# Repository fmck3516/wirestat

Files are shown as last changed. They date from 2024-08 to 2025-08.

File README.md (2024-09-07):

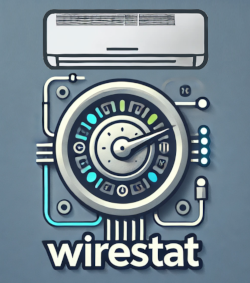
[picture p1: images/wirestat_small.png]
wirestat


# wirestat

## What is it?

wirestat is a compact gadget that bridges the gap between traditional wired household thermostats and ductless mini split
systems. With wirestat, you can control your mini split using familiar thermostats, whether it's an old-school thermostat
like Honeywell or a smart thermostat like Nest or Ecobee.

Why did I create wirestat?

- I wanted a consistent thermostat experience for my central AC and mini splits.
- I prefer traditional thermostats to smartphone apps and remote controls.
- I was frustrated by the lack of precise control over temperature swings and other settings.
- Ultimately, I wished I could use a regular household thermostat for my mini split.

## What is it not?

wirestat is not another smart thermostat. It is actually pretty dumb: 
- No buttons.
- No app.
- No internet.

## Is it for sale?

At this point in time, wirestat is a DIY project: All parts have to be sourced and assembled
yourself. I might create and sell a small batch at cost some time in the future. Please get in
touch with me (see contact section below) if you are interested in a physical copy.

## How does it work?

wirestat continuously monitors your thermostat. When it detects a call (e.g., a call for cooling), it relays the command
to your mini split's indoor unit (IDU) via an infrared signal.

Examples:
- Thermostat calls for Stage 1 Cooling -> send "Cool / 70 Degree / Fan Low" to IDU
- Thermostat calls for Stage 2 Cooling -> send "Cool / 70 Degree / Fan Auto" to IDU
- Thermostat calls for Fan => send "Fan Auto" to IDU

## Media

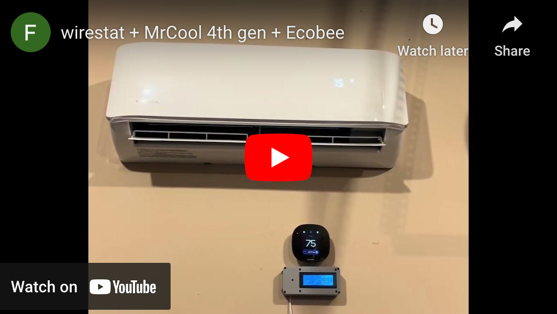
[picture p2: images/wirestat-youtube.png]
wirestat video (http://www.youtube.com/watch?v=b3PyWUqDRN4 "wirestat + MrCool 4th gen + Ecobee")


wirestat in action

wirestat disassembled

### Configuration

wirestat supports the following inputs:

| Symbol | Descr |
|---|---|
| G1 | Fan (stage 1) |
| G2 | Fan (stage 2) |
| G3 | Fan (stage 3) |
| Y1 | Cooling (stage 1) |
| Y2 | Cooling (stage 2) |
| W1 | Heating (stage 1) |
| W2 | Heating (stage 2) |

It's fine if you thermostat does not support all of the above inputs. If you thermostat only supports a single stage for
fan, cooling and heating, you only need to wire G1, Y1 and W1.

Each relevant input scenario is mapped to an infrared signal for the IDU.

Example:

| G1  | G2  | G3  | Y1  | Y2  | W1  | W2  | Infrared Signal for IDU |
|-----|-----|-----|-----|-----|-----|-----|---|
| 0 | 0 | 0 | 0 | 0 | 0 | 0 | OFF |
| 1 | 0 | 0 | 0 | 0 | 0 | 0 | Fan (low) |
| ... | ... | ... | ... | ... | ... | ... | ... |
| 0/1 | 0/1 | 0/1 | 1 | 0 | 0 | 0 | Cool (72F) / Fan (low)  |
| 0/1 | 0/1 | 0/1 | 0 | 1 | 0 | 0 | Cool (72F) / Fan (high) |
| ... | ... | ... | ... | ... | ... | ... | ... |

# Resources

## :warning: Warning :warning:

wirestat is an experimental hobby project. I've put it together without a background in electrical engineering - use the
provided circuit, firmware and enclosure at your own risk.

## Firmware

The firmware was developed using the [Arduino IDE](https://www.arduino.cc/en/software).

Source: [wirestat.ino](firmware/wirestat/wirestat.ino)

## Schematics

The schematics were drawn in [KiCad](https://www.kicad.org). 

Source: [wirestat.kicad_sch](schematics/wirestat.kicad_sch)

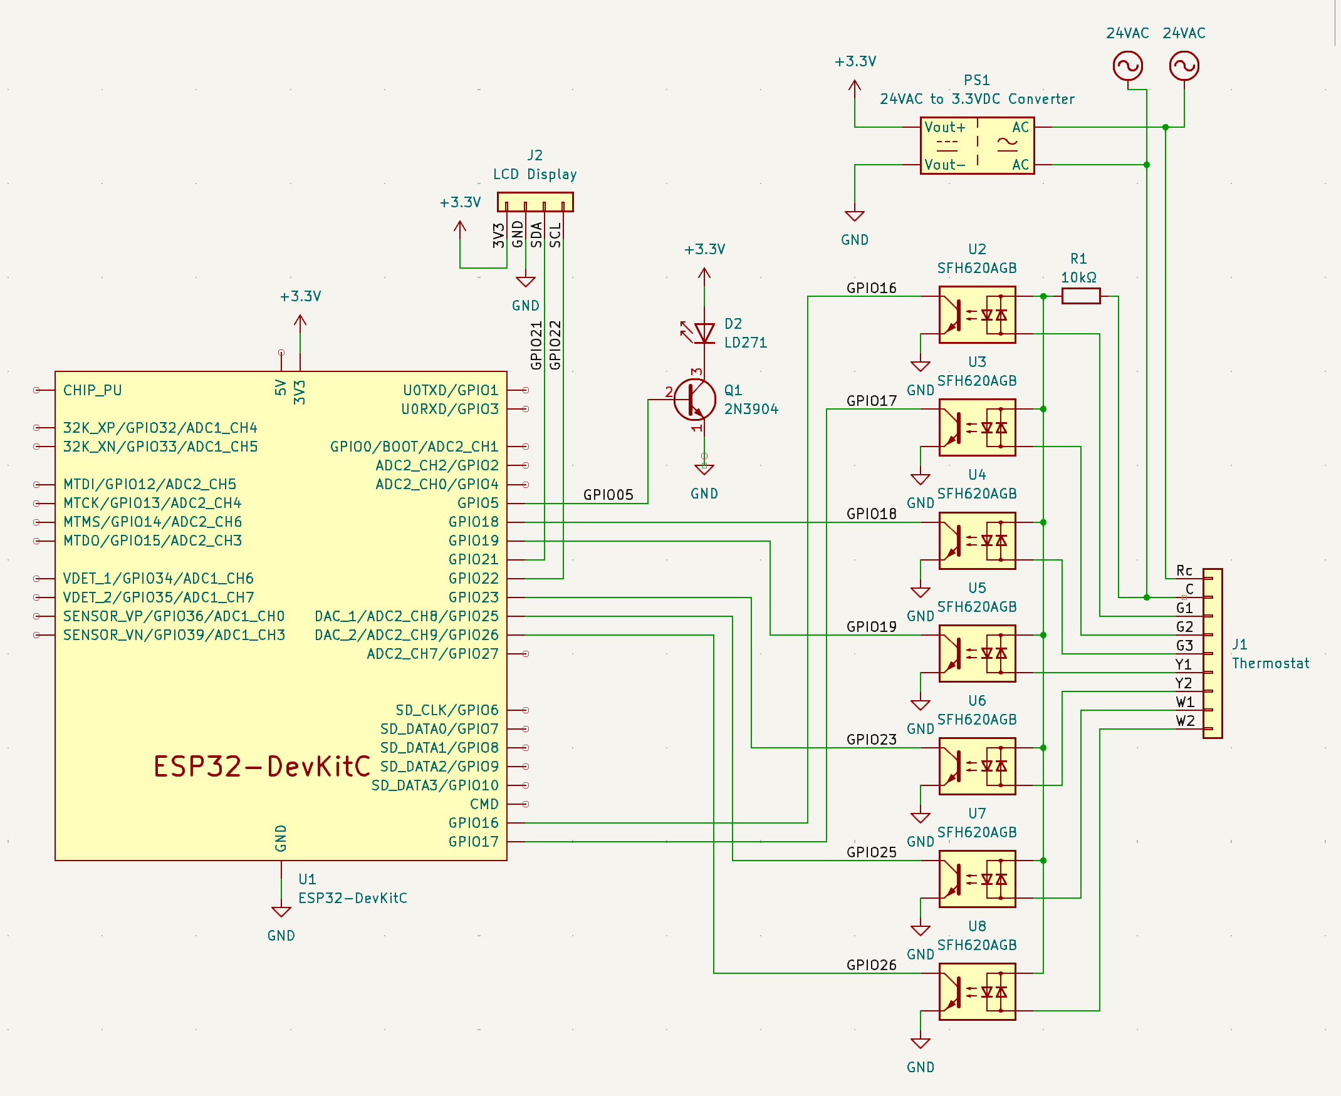
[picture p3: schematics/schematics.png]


## Enclosure

The enclosure was designed in [Blender](https://www.blender.org) and printed on a
[Bambu Lab X1 Carbon](https://bambulab.com/en-us/x1) 3D printer.

Blender file:
- [enclosure.blend](enclosure/enclosure.blend)

STL exports:
- [base.stl](enclosure/base.stl)
- [lid.stl](enclosure/lid.stl)
- [thermostat-cover-plate.stl](enclosure/thermostat-cover-plate.stl)

## Power Supply

wirestat operates on a 24V AC input, making it fully compatible with the standard power supply used by regular household
thermostats.

You have two options to power wirestat:

- Utilize the existing power supply of your thermostat, or
- Purchase an [AC 24 Volt Transformer](https://www.amazon.com/dp/B07DJ7RHS5) to power both wirestat and your thermostat.

## Parts List

I've sources some components (e.g., the transistor and infrared LED) from existing boards and Arduino starter kits. 
Accordingly, I do not have a datasheet for those components.  

| Symbol | Confirmed | Description | Count | Unit Price | Total  |
|---|---|---|---|---|---|
| U1 | :white_check_mark: | [ESP32 Development Board](https://www.amazon.com/gp/product/B0718T232Z) | 1 | $9.99 | $9.99  |
| U2-U8  | :white_check_mark: | [SFH620AGB Optoinsulator](https://www.digikey.com/en/products/detail/vishay-semiconductor-opto-division/SFH620AGB/4074947) | 7 | n/a | $4.22  |
| R1 | :white_check_mark: | [10 kΩ Resistor](https://www.digikey.com/en/products/detail/yageo/MF0207FRE52-10K/9124672) | 1 | $0.10 | $0.10  |
| Q1 | :grey_question: | [2N3904 NPN Transistor](https://www.digikey.com/en/products/detail/diotec-semiconductor/2N3904/13164701) | 1 | $0.13 | $0.13  |
| D2 | :grey_question: | [IR LED 940NM](https://www.digikey.com/en/products/detail/lumex-opto-components-inc/OED-EL-1L2/270797) | 1 | $0.58 | $0.58  |
| PS1 | :white_check_mark: | [AC to DC Buck Step Down Converter](https://www.amazon.com/dp/B0983GW7YJ) | 1 | n/a | $8.99  |
| PS1 | :white_check_mark: | [20x4 I2C LCD Module](https://www.amazon.com/dp/B01GPUMP9C) | 1 | $12.99 | $12.99 |

# Reverse engineering of infrared commands

I used [IRrecvDumpV2](https://github.com/crankyoldgit/IRremoteESP8266/blob/master/examples/IRrecvDumpV2/IRrecvDumpV2.ino)
to reverse engineer the infrared commands for my indoor unit.

# Open Questions

## Resistors for the infrared LED

Based on my little bit of research, it is required to include the following resistors:

- A ~220Ω resistor between GPIO 5 and the transistor's base.
- A ~22Ω resistor between +3.3V and the infrared LED's anode.

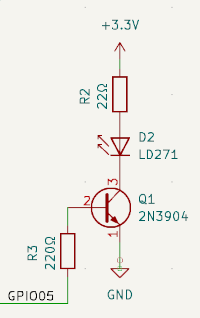
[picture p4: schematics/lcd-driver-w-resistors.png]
LCD driver with resistors


However, the circuit suggested in the [IR Sending](https://github.com/crankyoldgit/IRremoteESP8266/wiki#ir-sending) 
guide connects the transistor and infrared LED directly to the pins of the NodeMCU board:

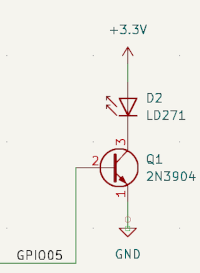
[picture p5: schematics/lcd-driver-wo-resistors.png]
LCD driver w/o resistors


The circuit operates effectively without resistors, and their absence notably extends the LED's range. I conducted a 
24-hour stress test, during which the circuit continuously transmitted infrared signals. Both the transistor and the LED
performed reliably throughout. Therefore, I've decided to proceed with the sub-circuit without resistors for now.

# References

- [Detecting 24V AC with an ESP32](https://www.youtube.com/watch?v=C4kNbcueWMxM)
- [IR Sending](https://github.com/crankyoldgit/IRremoteESP8266/wiki#ir-sending)

# Contributions / Contact

Contributions are always welcome! You can either

- submit a pull request,
- create an issue in GitHub's issue tracker or
- reach out via email at ${firstname}.${lastname}@gmail.com (replacement of placeholders left as exercise to the reader).

I would love to hear from you.

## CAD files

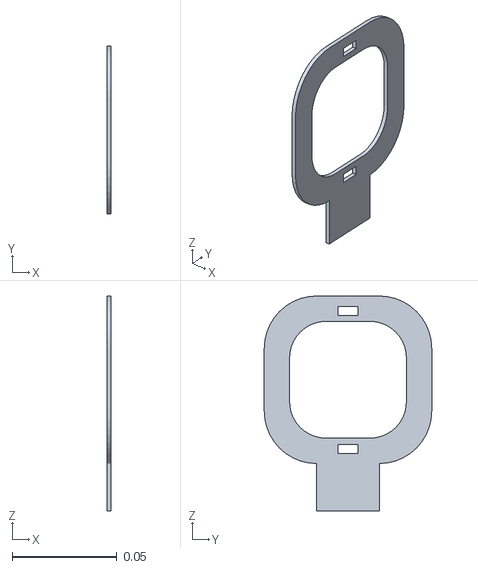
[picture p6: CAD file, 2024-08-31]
enclosure/thermostat-cover-plate.stl
0.002 x 0.08 x 0.103

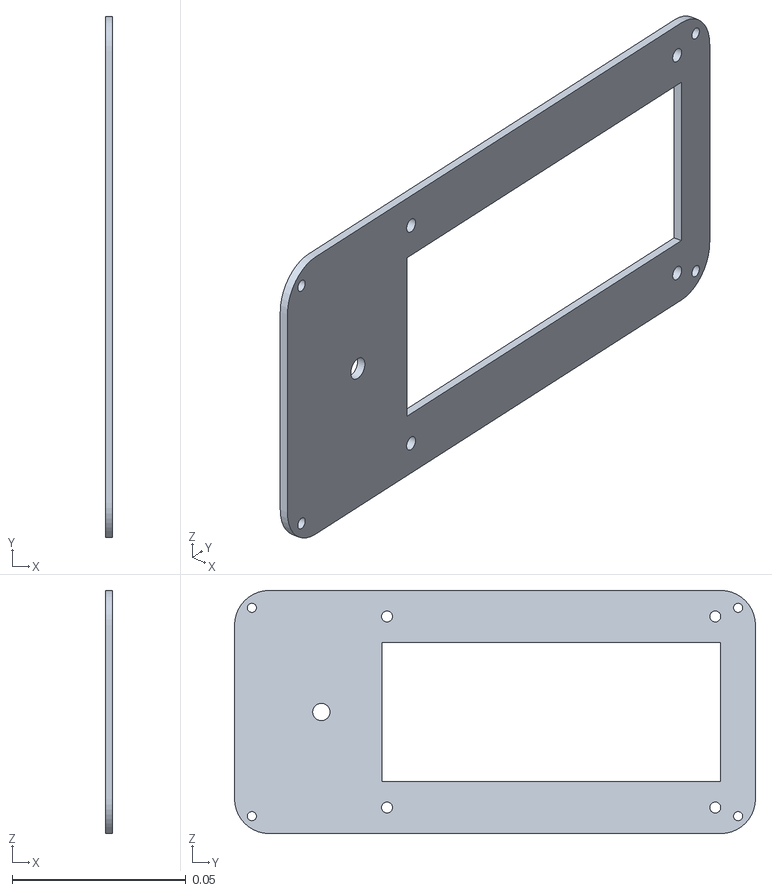
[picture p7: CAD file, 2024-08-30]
enclosure/lid.stl
0.002 x 0.15 x 0.07

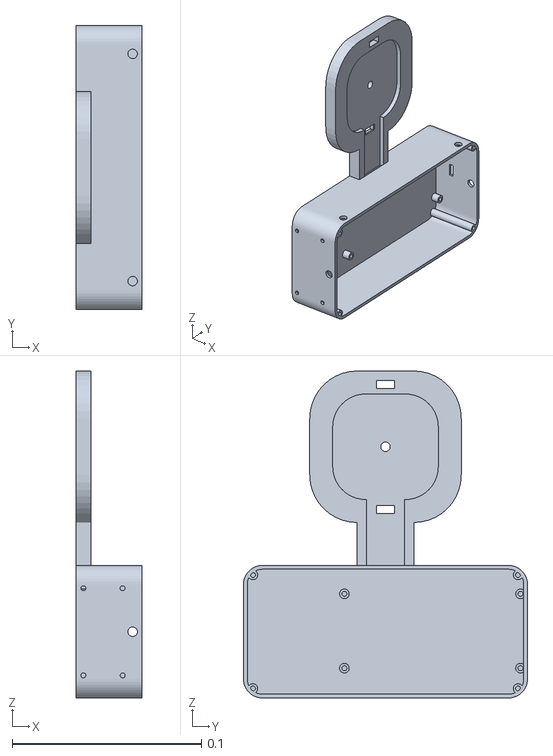
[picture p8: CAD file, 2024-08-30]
enclosure/base.stl
0.035 x 0.15 x 0.173

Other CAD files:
enclosure/enclosure.blend

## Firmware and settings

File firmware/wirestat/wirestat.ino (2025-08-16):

/*
  Copyright 2024 the original author or authors.

  Licensed under the Apache License, Version 2.0 (the "License");
  you may not use this file except in compliance with the License.
  You may obtain a copy of the License at

    https://www.apache.org/licenses/LICENSE-2.0

  Unless required by applicable law or agreed to in writing, software
  distributed under the License is distributed on an "AS IS" BASIS,
  WITHOUT WARRANTIES OR CONDITIONS OF ANY KIND, either express or implied.
  See the License for the specific language governing permissions and
  limitations under the License.
*/

#include <IRremoteESP8266.h>
#include <IRsend.h>
#include <LiquidCrystal_I2C.h>

const uint16_t PIN_IR_TRANSMITTER = 5;
const uint16_t PIN_SDA = 21;
const uint16_t PIN_SCL = 22;
const uint16_t PIN_THERMOSTAT[] = {
  16 /* G1 */, 
  17 /* G2 */, 
  18 /* G3 */, 
  19 /* Y1 */, 
  23 /* Y2 */, 
  25 /* W1 */, 
  26 /* W2 */ 
};

const int DEBOUNCE_INTERVAL_MS = 2000;

long long PIN_LAST_ACTIVE[] = { 
  -DEBOUNCE_INTERVAL_MS /* G1 */, 
  -DEBOUNCE_INTERVAL_MS /* G2 */, 
  -DEBOUNCE_INTERVAL_MS /* G3 */, 
  -DEBOUNCE_INTERVAL_MS /* Y1 */, 
  -DEBOUNCE_INTERVAL_MS /* Y2 */, 
  -DEBOUNCE_INTERVAL_MS /* W1 */, 
  -DEBOUNCE_INTERVAL_MS /* W2 */ 
};

const int G1 = 0;
const int G2 = 1;
const int G3 = 2;
const int Y1 = 3;
const int Y2 = 4;
const int W1 = 5;
const int W2 = 6;

const int CALL_UNKNOWN = 0;
const int CALL_OFF = 1;
const int CALL_FAN = 2;
const int CALL_COOL_STAGE_1 = 3;
const int CALL_COOL_STAGE_2 = 4;
const int CALL_HEAT_STAGE_1 = 5;
const int CALL_HEAT_STAGE_2 = 6;

const int LCD_COLUMNS = 20;
const int LCD_ROWS = 4;
const int LCD_ADDRESS = 0x27;

/*
  The number of calls to store. Must be at least 2 to store
  - the candidate call and
  - the active call
*/
const int CALL_HISTORY = 5;

/*
  History of the last ${CALL_HISTORY} calls:

  call[0]: the candidate call (that might be promoted to active or replaced with the next candidate call)
  call[1]: the active call
  call[2]: the previous call
  call[3]: the pre-previous call
  ...
*/
int call[CALL_HISTORY];

/*
  The timestamps when the calls started. 
*/
unsigned long callStart[CALL_HISTORY];

const int CALL_IDX_CAND = 0;
const int CALL_IDX_ACTIVE = 1;
const int CALL_IDX_PREV = 2;
const int CALL_IDX_PPRV = 3;
const int CALL_IDX_P3RV = 4;

const unsigned long RESEND_INTERVAL =  1UL *  1UL * 15UL * 60UL * 1000UL; // 15 minutes
const unsigned long REBOOT_INTERVAL =  7UL * 24UL * 60UL * 60UL * 1000UL; // 7 days

unsigned long lastMessageSentAt = 0;

IRsend irsend(PIN_IR_TRANSMITTER);
LiquidCrystal_I2C lcd(0x27, LCD_COLUMNS, LCD_ROWS);

//
// The following codes have been recorded using https://github.com/crankyoldgit/IRremoteESP8266
//
const uint64_t MR_COOL_GEN4_OFF =                 0xA10C7EFFFFF3;
const uint64_t MR_COOL_GEN4_FAN_LOW =             0xA18C7EFFFF73;
const uint64_t MR_COOL_GEN4_COOL_75F_FAN_LOW =    0xA1886DFFFF6D;
const uint64_t MR_COOL_GEN4_COOL_75F_FAN_MEDIUM = 0xA1906DFFFF7D;
const uint64_t MR_COOL_GEN4_HEAT_75F_FAN_LOW =    0xA18B6DFFFF6F;
const uint64_t MR_COOL_GEN4_HEAT_75F_FAN_HIGH =   0xA19B6DFFFF77;


void setup() {
  irsend.begin();
  Serial.begin(115200, SERIAL_8N1);
  for (int i = 0; i < sizeof call / sizeof call[0]; i++) {
    call[i] = CALL_UNKNOWN;
    callStart[i] = 0;
  }
  for (int i = 0; i < sizeof PIN_THERMOSTAT / sizeof PIN_THERMOSTAT[0]; i++) {
    pinMode(PIN_THERMOSTAT[i], INPUT_PULLUP);
  }
  lcd.init();
  lcd.backlight();
  lcd.clear();  
}

void loop() {
  readThermostat();
  displayCallHistory();

  // reboot every week
  if (millis() >= REBOOT_INTERVAL) {
    ESP.restart();
  }

  // repeat current call every 15 minutes since the transmission is not 100% reliable
  if (millis() - lastMessageSentAt >= RESEND_INTERVAL) {
    sendMessage();
  }

  delay(100);
}

void readThermostat() {
  bool callG1 = checkThermostatPin(G1);
  bool callG2 = checkThermostatPin(G2);
  bool callG3 = checkThermostatPin(G3);
  bool callY1 = checkThermostatPin(Y1);
  bool callY2 = checkThermostatPin(Y2);
  bool callW1 = checkThermostatPin(W1);
  bool callW2 = checkThermostatPin(W2);

  if (!callG1 && !callY1 && !callY2 && !callW1 && !callW2) {
    processCallFromThermostat(CALL_OFF);
    return;
  }
  if (callG1 && !callY1 && !callY2 && !callW1 && !callW2) {
    processCallFromThermostat(CALL_FAN);
    return;
  }
  if (callY1 && !callY2) {
    processCallFromThermostat(CALL_COOL_STAGE_1);
    return;
  }
  if (callY2) {
    processCallFromThermostat(CALL_COOL_STAGE_2);
    return;
  }
  if (callW1 && !callW2) {
    processCallFromThermostat(CALL_HEAT_STAGE_1);
    return;
  }
  if (callW2) {
    processCallFromThermostat(CALL_HEAT_STAGE_2);
    return;
  }
}

void displayCallHistory() {
  displayCall(0, CALL_IDX_ACTIVE, "CURR");
  displayCall(1, CALL_IDX_PREV, "PREV");
  displayCall(2, CALL_IDX_PPRV, "PPRV");
  displayCall(3, CALL_IDX_P3RV, "P3RV");
}

void displayCall(int line, int callIndex, String prefix) {
  lcd.setCursor(0, line);
  switch (call[callIndex]) {
    case CALL_OFF:
      lcd.print(prefix + ": OFF  ");
      break;
    case CALL_FAN:
      lcd.print(prefix + ": FAN  ");
      break;
    case CALL_COOL_STAGE_1:
      lcd.print(prefix + ": COOL1");
      break;
    case CALL_COOL_STAGE_2:
      lcd.print(prefix + ": COOL2");
      break;
    case CALL_HEAT_STAGE_1:
      lcd.print(prefix + ": HEAT1");
      break;
    case CALL_HEAT_STAGE_2:
      lcd.print(prefix + ": HEAT2");
      break;      
    default:
      lcd.print(prefix + ": -    ");
      break;
  }
  lcd.setCursor(12, line);
  lcd.print(formatTime(callStart[callIndex], callIndex == CALL_IDX_ACTIVE ? millis() : callStart[callIndex - 1]));
}

bool checkThermostatPin(int pinIndex) {
  bool active = 0 == digitalRead(PIN_THERMOSTAT[pinIndex]); 
  if (active) {
    PIN_LAST_ACTIVE[pinIndex] = millis();
  }
  /*
    If there was at least one call within the last ${DEBOUNCE_INTERVAL_MS} milliseconds, consider the pin to be called.
  
    The AC waveform that is fed into the optoinsulator results in intermittent false negatives when treating
    the output as digital signal. The time based heuristic eliminates the need for a capacitor to smoothen the
    output signal.
  */
  return (millis() - PIN_LAST_ACTIVE[pinIndex]) < DEBOUNCE_INTERVAL_MS;
}

void processCallFromThermostat(int callFromThermostat) {
  /*
    A newly detected call from the thermostat is first treated as a "candidate call".

    Let's consider an example to understand the purpose of candidate calls:

    t=  0: thermostat calls for off
    t=100: thermostat calls for COOL Stage 2 (Y1 + Y2)

    The AC waveform that is fed into the optoinsulators and the timing of code executed can result in the following
    calls from the thermostat to be observed:

    t=  1: wirestat detects call OFF          (all pins inactive)
    t=101: wirestat detects call COOL Stage 1 (Y1 active / Y2 inactive)
    t=102: wirestat detects call COOL Stage 2 (Y1 active / Y2 active)

    The thermostat never calls for COOL Stage 1. However, wirestat detects this call because there is a moment in time 
    where it reads Y1 as active and Y2 as inactive. Shortly afterwards, Y2 reads as active and the intended call 
    (COOL Stage 2) is detected.

    Treating newly detected calls as candidates allows wirestat to filter out "phantom calls" like COOL Stage 1 in the 
    above example.
  */
  if (call[CALL_IDX_CAND] != callFromThermostat) {
      
    call[CALL_IDX_CAND] = callFromThermostat;
    callStart[CALL_IDX_CAND] = millis();
    
  } else {    

    /*
      If the candidate call is detected for a time period longer than ${DEBOUNCE_INTERVAL_MS}, it is promoted to be the
      next active call.
    */
    bool promoteCandidateToActive = call[CALL_IDX_CAND] != call[CALL_IDX_ACTIVE] &&
      (millis() - callStart[CALL_IDX_CAND] > DEBOUNCE_INTERVAL_MS);
    if (promoteCandidateToActive) {
      
      /*
        Shift the history to make room for the new active call.
      */
      for (int i = CALL_HISTORY - 1; i >= 2; i--) {
        call[i] = call[i - 1];
        callStart[i] = callStart[i - 1];
      }
      
      /*
        Promote the candidate to active.
      */
      call[CALL_IDX_ACTIVE] = call[CALL_IDX_CAND];
      callStart[CALL_IDX_ACTIVE] = millis();
      
      /*
        Send new active call to the indoor unit.
      */
      sendMessage();
    }    
  }
}

void sendMessage() {
    lastMessageSentAt = millis();
    switch (call[CALL_IDX_ACTIVE]) {
      case CALL_OFF:
        Serial.println("Sending message for CALL_OFF.");
        irsend.sendMidea(MR_COOL_GEN4_OFF);
        break;
      case CALL_FAN:
        Serial.println("Sending message for FAN.");
        irsend.sendMidea(MR_COOL_GEN4_FAN_LOW);
        break;
      case CALL_COOL_STAGE_1:
        Serial.println("Sending message for COOL_STAGE_1.");
        irsend.sendMidea(MR_COOL_GEN4_COOL_75F_FAN_LOW);
        break;
      case CALL_COOL_STAGE_2:
        Serial.println("Sending message for COOL_STAGE_2.");
        irsend.sendMidea(MR_COOL_GEN4_COOL_75F_FAN_MEDIUM);
        break;
      case CALL_HEAT_STAGE_1:
        Serial.println("Sending message for HEAT_STAGE_1.");
        irsend.sendMidea(MR_COOL_GEN4_HEAT_75F_FAN_LOW);
        break;
      case CALL_HEAT_STAGE_2:
        Serial.println("Sending message for HEAT_STAGE_2.");
        irsend.sendMidea(MR_COOL_GEN4_HEAT_75F_FAN_HIGH);
        break;        
  }
}

String formatTime(unsigned long start, unsigned long end) {
  if (start == 0) {
    return "        ";
  }
  unsigned long seconds = (end - start) / 1000;
  unsigned long minutes = seconds / 60;
  unsigned long hours = minutes / 60;

  seconds = seconds % 60;
  minutes = minutes % 60;
  hours = hours % 24;

  char timeString[9];  // HH:MM is 5 characters + null terminator
  sprintf(timeString, "%02lu:%02lu:%02lu", hours, minutes, seconds);

  return String(timeString);
}

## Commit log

2024-08-30 more work on schematics and enclosure
    [base.stl, enclosure.blend, lid.stl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]
2024-08-31 enclosure: more work on schematics and enclosure
    [enclosure.blend, thermostat-cover-plate.stl]
2024-09-01 more work
    [enclosure.blend]
2024-09-10 filter out calls < DEBOUNCE_INTERVAL_MS
2024-09-22 firmware: switch from raw bytes to 48 bit commands
2024-12-01 firmware: added support for heat 1 / 2
2025-01-24 firmware: change stage 2 heating to high fan speed
2025-08-16 added resend / reboot functionality
    [wirestat.ino]
